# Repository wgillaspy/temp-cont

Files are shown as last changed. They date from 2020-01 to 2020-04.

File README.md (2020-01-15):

# temp(erature)-cont(roller)

An very small atemga328p based temperature controller that can be used to incubate animals :lizard: :honeybee: :hatching_chick: and plants :rose: :cactus:. 

It uses up to five ds18b20 temperature probes connected into a single audio jack to monitor temperature.
Heating can be provided through a 5v-12vDC heating source.  I use the 12v rail of a spare computer power supply.

The board connects to any computer over usb serial and prints the temperature statuses in Json about every second.  The 
default target temperature can be changed while running and is stored in EEPROM to survive power offs.  The target temperature 
can also be set without writing to EEPROM.  This is useful when using a secondary application to maintain a temperature profile.
Right now the temperature can only be set with integers.
 
Programming of the atmega is done over a mini-usb (ftdi) or via the isp headers.

##### Setting the target temperature

Set the target temperature to 91F and write the value to EEPROM to persist across power offs.
```json
{"a":"tgt","tgt":91} 
```

Set the target temperature to 100F and **do not** write the value to EEPROM.  The target temperature will revert back to what is stored in EEPROM if powered off and back on.
```json
{"a":"tgt_tmp","tgt":100}
``` 

##### Reading the output
Every second or so, the board sends a json string so you know the status of your incubator.  t0 and t1 are the two 
temperatures probes (the code allows up to five).  Avg is the probe's temperature averaged together.  It's the temperature
used to compare against the tgt value.  Ht is whether the heater mostfet is on or not.  And fan is the number of pulses received between readings.  If the pulse fall to zero, the heating element will be disabled to prevent overheating.
```json
{ "tgt": "81",
  "t0": "80.60",
  "t1": "81.50",
  "avg": "81.05",
  "ht": "0",
  "fan": "126" }
``` 

Top layer of the board, about life size.  
Board Top

The controller board is hooked up to a raspberry pi running the [nodejs controller](nodejs/src/main/controller) container which
maintains a temperature profile and sends the output of the board to a personal splunk instance for graphing.   
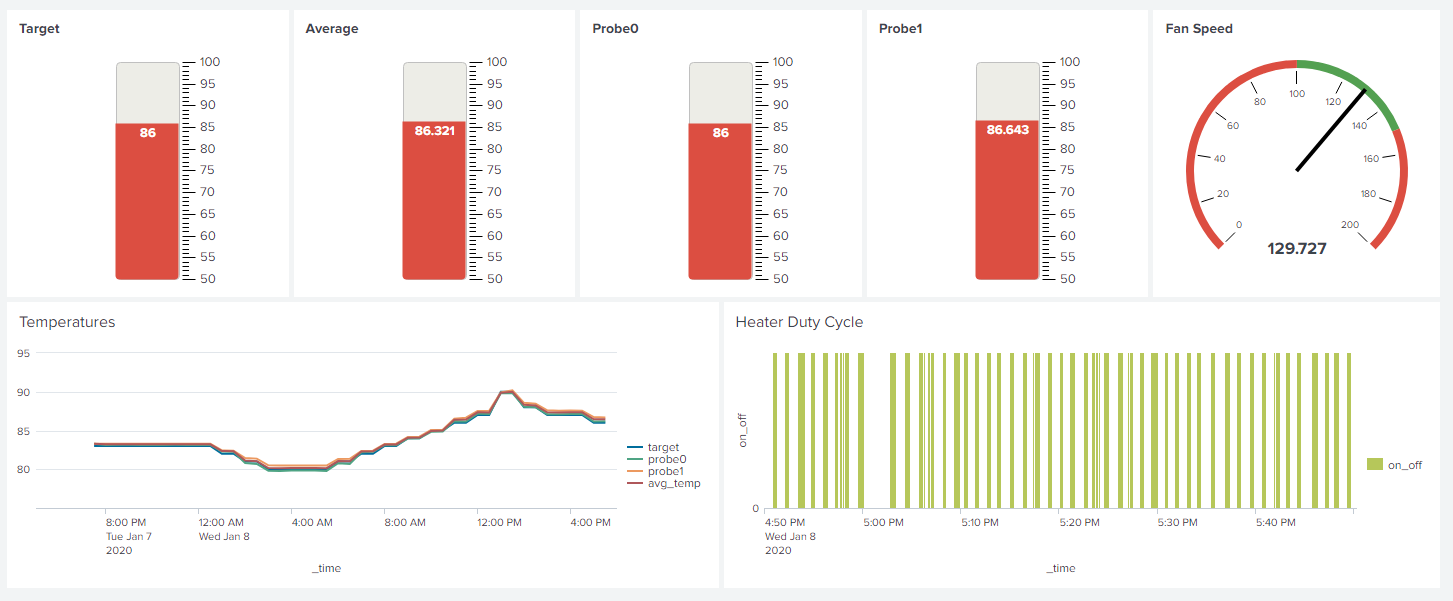
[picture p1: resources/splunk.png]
SplunkPanel


How updates are deployed.

- Board code is tested locally on the workstation and once confirmed as working then
- The code is pushed to github.
- The github webhook calls out to Jenkins on the same private network as the temperature controller.
- The Jenkins instance creates a build container
- The build container then packages up the arduino code into an [avr-dude container](https://github.com/wgillaspy/arm64v8-avrdude) and sends it to a raspberry pi that the temperature controller is connected to via usb.
- The build container requests that the container start then
- At container start, the temperature controller code is compiled within the avr-dude container on the remote raspberry pi and then deployed to the temperature controller board.

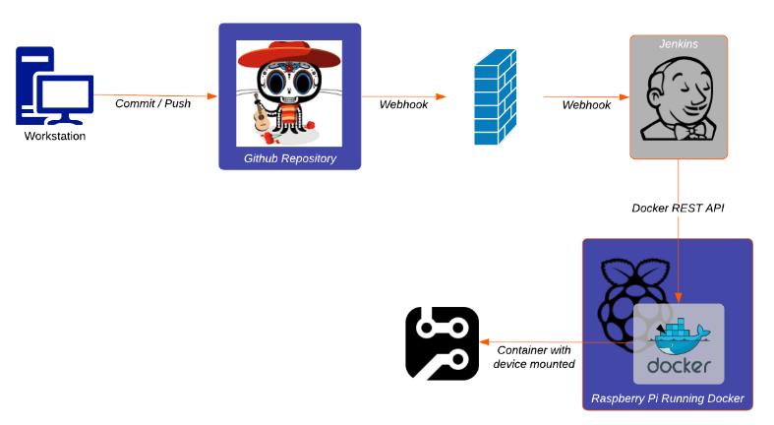
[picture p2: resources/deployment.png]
Deploy


Why the additional complexity with docker?  Mostly to take advantage of an immutable system that is easy to recover.
If the raspberry pi SD fails (which they infrequently do) I can quickly stand up a new raspberry pi with the docker REST api exposed using a simple ansible script.
Once the REST api is exposed and the raspberry pi is placed back on the network, jenkins can deploy both the temperature controller board code (if necessary) and the application that manages the temperature profile.

Since I don't keep my incubator near my workstation, having a deployment pipeline that can update both the firmware and
secondary application that controls the temperature profile to remote locations is super awesome.  I don't have to lug
my laptop around just to add a feature or set a default temperature.

Hopefully some portion of this project will be useful to you :)  

#### New Things
- [x] Add SMS notifications.
- [x] Update the NodeJs application to write to a splunk endpoint. 

#### :building_construction: Board changes.
- [x] Remove the serial display jumper in favor of another 5V fan jumper.  
- [x] Add an additional mosfet for the additional fan.
- [x] Better isolate the two fan jumpers, provide their own 5v separate from atmega board to reduce noise.  
- [x] Move the mosfet gate pins onto analog output pins.  Right now the heater can only be off or on.
- [x] Remove the ftdi programmer pads from the bottom of the board.
- [x] Add a jumper for the heater mosfet gate that can be used to drive an external AC mosfet. (feature/new-board-layout)

#### Upcoming board changes
- [ ] Convert the mini usb connector to usb c.
- [ ] Update the BOM and pad sizes to be consistent across components.
- [ ] Does 0402 makes sense?  
- [ ] Retrace the board to reduce overall board size.
- [ ] Figure out compatibility issues with atmega328pb

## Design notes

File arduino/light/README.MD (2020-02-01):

Analog Out / TIMER / PWM Pins

- 2  PD2 - FAN INT 1
- 3  PD3 - FAN INT 2
- 5  PD5 - HEATER GATE
- 6  PD6 - FAN GATE 1
- 9  PB1 - FAN GATE 2
- 10 PB2 - SS
- 11 PB3 - MOSI

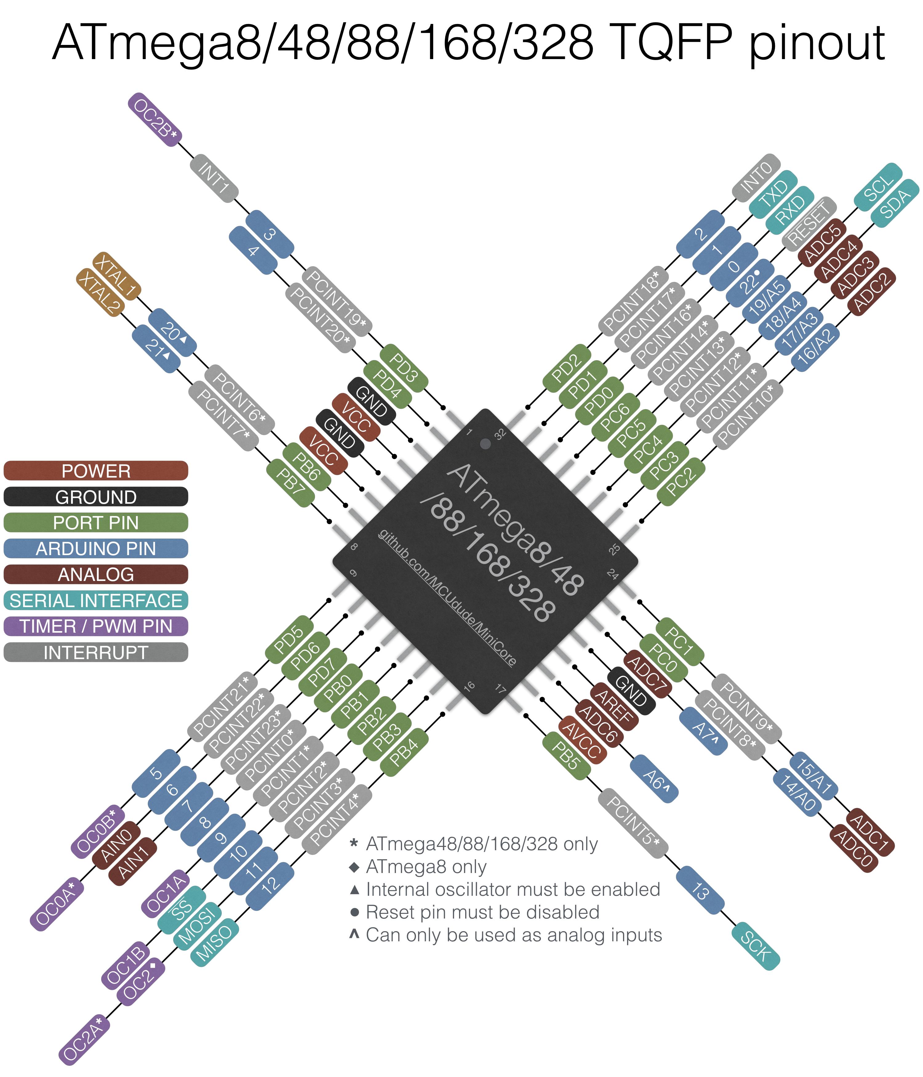
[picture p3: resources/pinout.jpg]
Atmega8


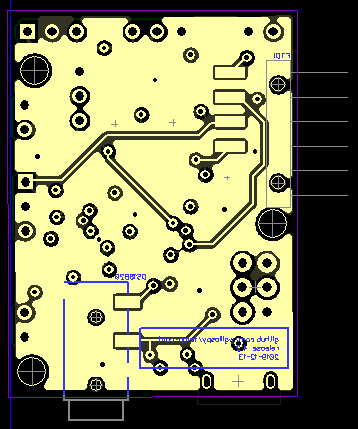
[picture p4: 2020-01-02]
resources/board-bottom.png

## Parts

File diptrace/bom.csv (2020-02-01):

Manufacturer | Name | Value | RefDes
 | JUMPER_2 |  | 12VDrain
 | JUMPER_3 |  | 5VFan
 | JUMPER_3 |  | 5VFan1
 | JUMPER_2 |  | 5VoltPower
Atmel | ATMEGA8_TQFP |  | ATMEGA
 | CAP0402-CAP | 0.1uF | C1
 | CAP0603-CAP | 0.1uF | C2
 | CAP0402-CAP | 0.1uF | C4
 | CAP0402-CAP | 10uF | C5
 | CAP0402-CAP | 10uF | C6
 | AUDIO-JACK3 | AUDIO-JACK3 | DS18B20
 | JUMPER_2 |  | ExtGate
 | JUMPER_3 |  | FANMOSFET
 | JUMPER_3 |  | FANMOSFET1
 | JUMPER_3 |  | HEATERMOSFET
 | AVR_SPI_PRG_6SMT_MALE | ICSP | ISP
 | LED_0603 | Blue | LED1
 | LED_0603 | Green | LED2
 | LED_0603 | Blue | LED3
 | LED_0603 | Blue | LED4
 | LED0603 (LED) | Red | LED5
 | LED0603 (LED) | Green | LED6
 | RESISTOR0402-RES | 10K | R1
 | RESISTOR0603-RES | 1k | R2
 | RESISTOR0603-RES | 1k | R3
 | RESISTOR0603-RES | 1k | R4
 | RESISTOR0603-RES | 1k | R5
 | RESISTOR0603-RES | 1k | R6
 | RESISTOR0603-RES | 1k | R7
 | RESISTOR0603-RES | 1k | R8
 | RESISTOR0603-RES (RESISTOR) | 1K | R9
 | RESISTOR0603-RES (RESISTOR) | 1K | R10
 | RES_0402 |  | R4.7K2
 | FT232RLSSOP (FT232RL) |  | U2
 | USB MICRO 609-4616-1 |  | U4
 | JUMPER_2 |  | VCC_FAN/GND
 | RESONATORSMD | 10k | Y1

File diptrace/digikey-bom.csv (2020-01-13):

Manufacturer Part Number | Manufacturer | Digi-Key Part Number | Customer Reference | Reference Designator | Packaging | Part Status | Quantity | Unit Price | Extended Price | Description | RoHS Status | Lead Free Status
C1608JB0J106K080AB | TDK Corporation | 445-11185-1-ND |  |  | Cut Tape (CT) | Active | 2 | 0.41 | $0.82 | CAP CER 10UF 6.3V JB 0603 | ROHS3 Compliant | Lead free
CL05A104MP5NNNC | Samsung Electro-Mechanics | 1276-1443-1-ND |  |  | Cut Tape (CT) | Active | 4 | 0.1 | $0.40 | CAP CER 0.1UF 10V X5R 0402 | ROHS3 Compliant | Lead free
CSTNE16M0VH3C000R0 | Murata Electronics | 490-17951-1-ND |  |  | Cut Tape (CT) | Active | 1 | 0.44 | $0.44 | CERAMIC RES 16.0000MHZ 15PF SMD | ROHS3 Compliant | Contains lead
FT232RL-REEL | FTDI, Future Technology Devices International Ltd | 768-1007-1-ND |  |  | Cut Tape (CT) | Active | 1 | 4.5 | $4.50 | IC USB FS SERIAL UART 28-SSOP | RoHS Compliant | Lead free
ERA-2AED103X | Panasonic Electronic Components | P10KDECT-ND |  |  | Cut Tape (CT) | Active | 2 | 0.22 | $0.44 | RES SMD 10K OHM 0.5% 1/16W 0402 | ROHS3 Compliant | Lead free
ERA-3AED102V | Panasonic Electronic Components | P123733CT-ND |  |  | Cut Tape (CT) | Active | 8 | 0.11 | $0.88 | RES SMD 1K OHM 0.5% 1/10W 0603 | ROHS3 Compliant | Lead free
10118193-0001LF | Amphenol ICC (FCI) | 609-4616-1-ND |  |  | Cut Tape (CT) | Active | 1 | 0.43 | $0.43 | CONN RCPT USB2.0 MICRO B SMD R/A | RoHS Compliant | Lead free
ERJ-3GEYJ472V | Panasonic Electronic Components | P4.7KGCT-ND |  |  | Cut Tape (CT) | Active | 1 | 0.1 | $0.10 | RES SMD 4.7K OHM 5% 1/10W 0603 | ROHS3 Compliant | Lead free
ATMEGA328P-AUR | Microchip Technology | ATMEGA328P-AURCT-ND |  |  | Cut Tape (CT) | Active | 1 | 2.08 | $2.08 | IC MCU 8BIT 32KB FLASH 32TQFP | ROHS3 Compliant | Lead free
IN-S63AT5B | Inolux | 1830-1061-1-ND |  |  | Cut Tape (CT) | Active | 1 | 0.34 | $0.34 | LED BLUE CLEAR 0603 SMD | ROHS3 Compliant | Lead free
IN-S63AT5G | Inolux | 1830-1062-1-ND |  |  | Cut Tape (CT) | Active | 2 | 0.52 | $1.04 | LED GREEN CLEAR 0603 SMD | ROHS3 Compliant | Lead free
IN-S63AT5Y | Inolux | 1830-1066-1-ND |  |  | Cut Tape (CT) | Active | 1 | 0.32 | $0.32 | LED YELLOW CLEAR 0603 SMD | ROHS3 Compliant | Lead free
IN-S63ATR | Inolux | 1830-1065-1-ND |  |  | Cut Tape (CT) | Active | 1 | 0.34 | $0.34 | LED RED CLEAR 0603 SMD | ROHS3 Compliant | Lead free
LO Q976-PS-25-0-20-R18 | OSRAM Opto Semiconductors Inc. | 475-2486-1-ND |  |  | Cut Tape (CT) | Active | 1 | 0.29 | $0.29 | LED ORANGE DIFFUSED 0603 SMD | ROHS3 Compliant | Lead free
FQP30N06L | ON Semiconductor | FQP30N06L-ND |  |  | Tube | Active | 3 | 1.22 | $3.66 | MOSFET N-CH 60V 32A TO-220 | ROHS3 Compliant | Lead free

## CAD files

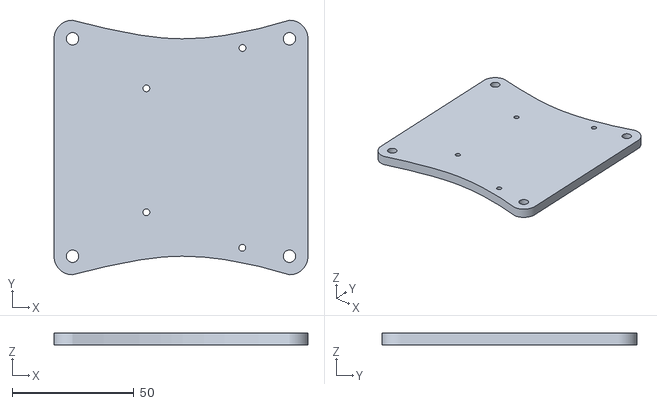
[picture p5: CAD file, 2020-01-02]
parts/new_stl/HangingMount.stl
104.3 x 104.5 x 5.08

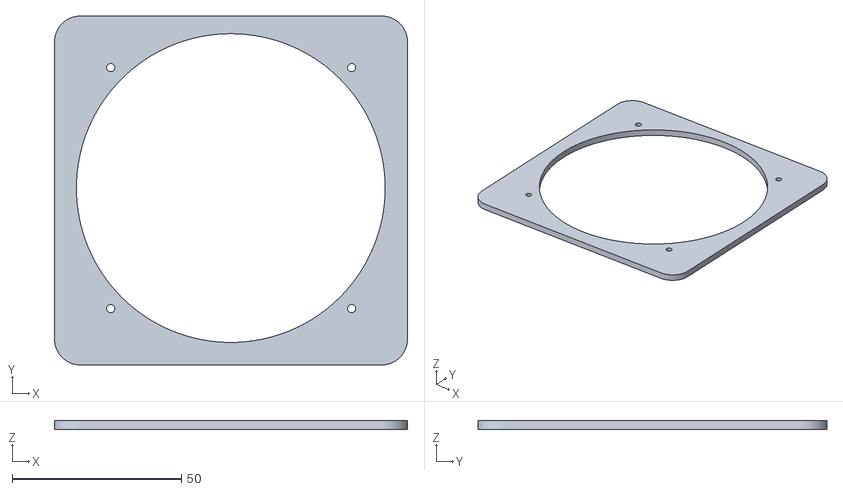
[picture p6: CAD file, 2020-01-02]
parts/new_stl/SHLargeFanTop.stl
104.2 x 103.0 x 2.54

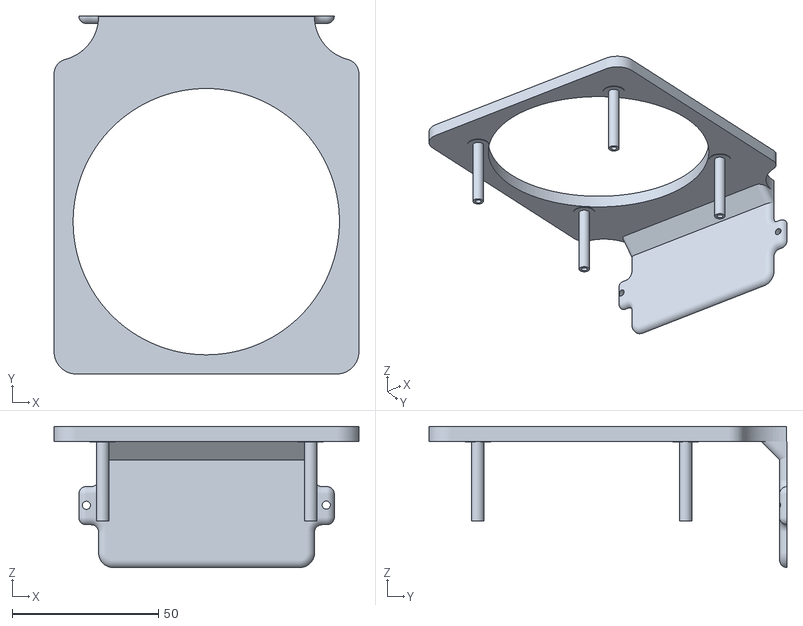
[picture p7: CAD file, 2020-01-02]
parts/new_stl/HeaterBaseInternal.stl
104.3 x 122.4 x 48.3

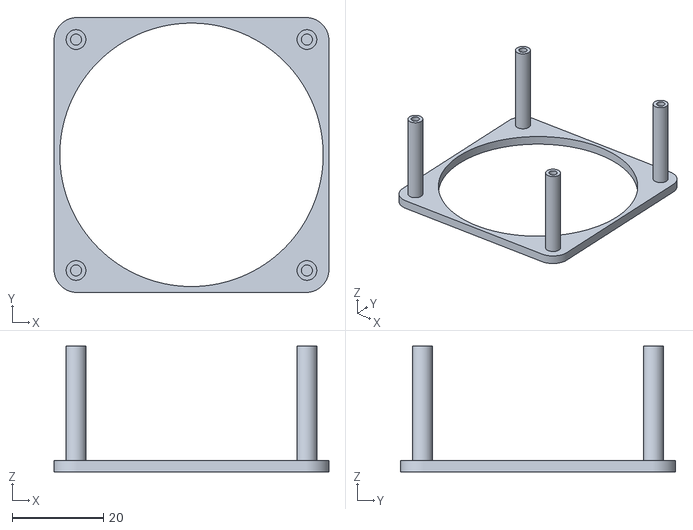
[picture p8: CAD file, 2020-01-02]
parts/new_stl/SHFanHolder.stl
60.2 x 60.2 x 27.6

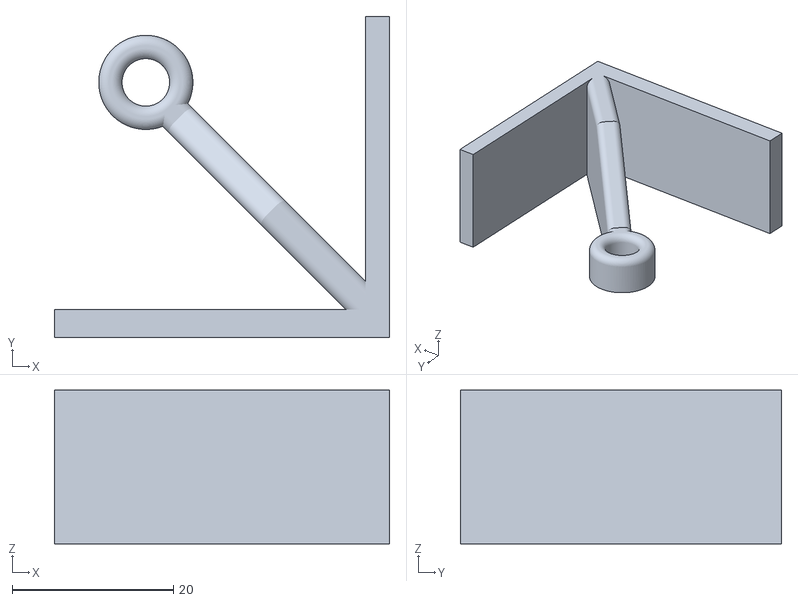
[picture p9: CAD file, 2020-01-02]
parts/new_stl/TempProbeHolder.stl
41.6 x 39.8 x 19.0

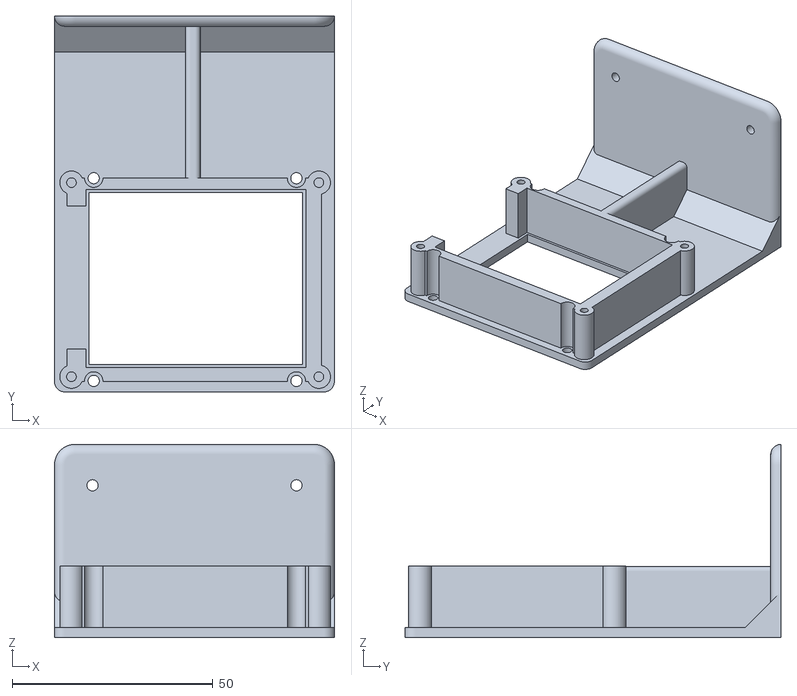
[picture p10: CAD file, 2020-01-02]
parts/new_stl/SHHeatElementHolder.stl
69.8 x 93.7 x 48.2

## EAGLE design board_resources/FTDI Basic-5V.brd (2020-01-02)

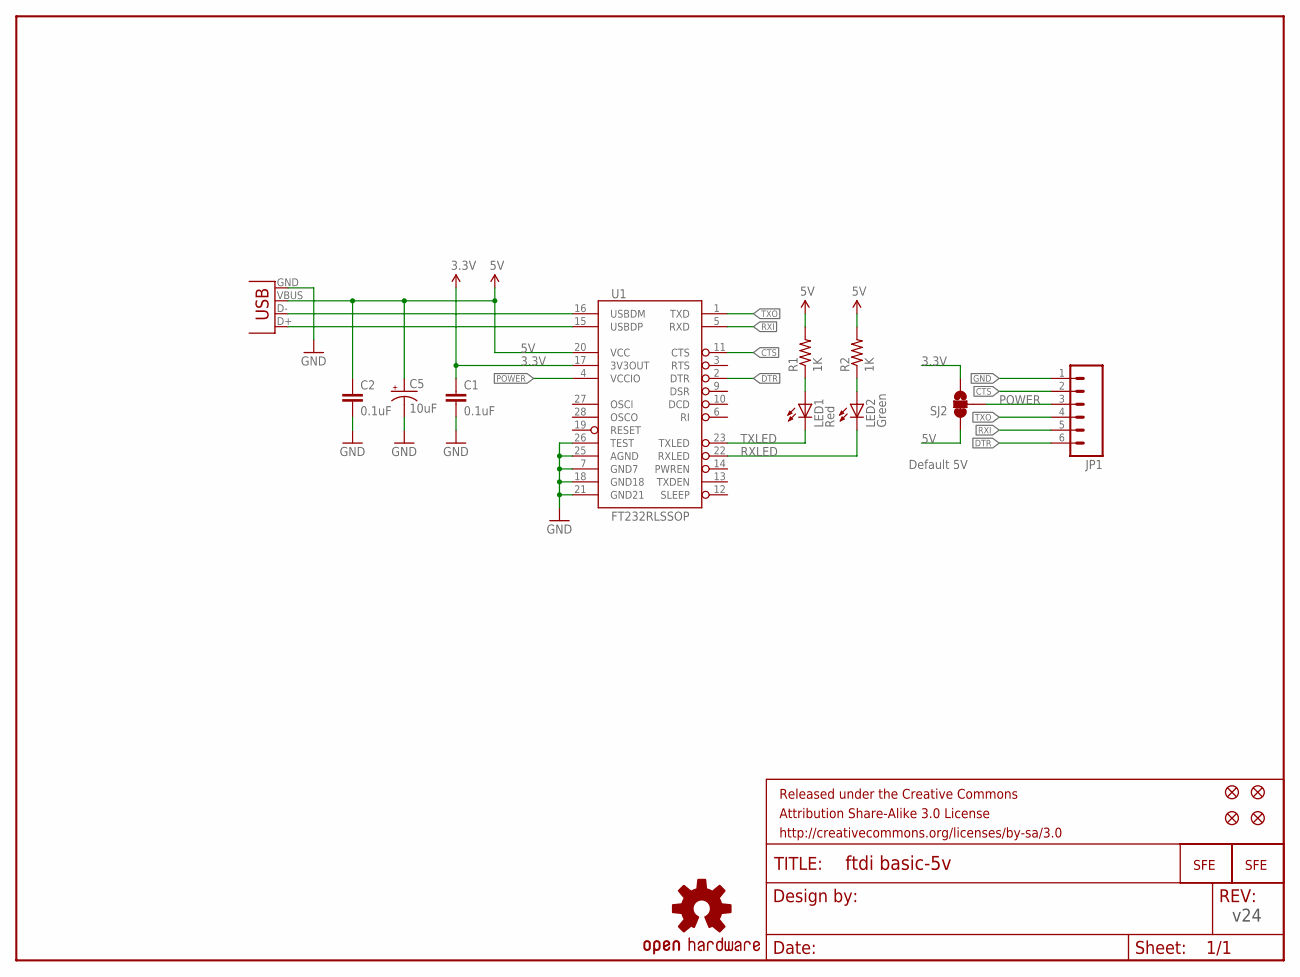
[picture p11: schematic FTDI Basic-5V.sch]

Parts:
C1, C2: 0.1uF; 0603-CAP
C5: 10uF; EIA3216
FRAME1: FRAME-LETTER; CREATIVE_COMMONS
JP1: M06SMD-FEMALE-V2; 1X06-SMD-FEMALE-V2
JP2: LOGO-SFESK; SFE-LOGO-FLAME
JP3, JP4, JP5, JP6: FIDUCIAL1X2; FIDUCIAL-1X2
LED1: Red; LED-0603
LED2: Green; LED-0603
LOGO1: OSHW-LOGOS; OSHW-LOGO-S
R1, R2: 1K; 0603-RES
SJ2: SOLDERJUMPER_2WAYS; SJ_3
U1: FT232RLSSOP; SSOP28DB
U$2: LOGO-SFENW2; SFE-NEW-WEB
X2: USB-SMD-NS; USB-MINIB-NOSTOP

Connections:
3.3V: C1.1, SJ2.3, U1.17 (3V3OUT)
5V: C2.1, C5.A (+), R1.2, R2.2, SJ2.1, U1.20 (VCC), X2.VBUS
CTS: JP1.2, U1.11 (CTS)
DTR: JP1.6, U1.2 (DTR)
GND: C1.2, C2.2, C5.C (-), JP1.1, U1.7 (GND7), U1.18 (GND18), U1.21 (GND21), U1.25 (AGND), U1.26 (TEST), X2.GND
unnamed: LED1.A, R1.1
unnamed: LED2.A, R2.1
POWER: JP1.3, SJ2.2, U1.4 (VCCIO)
RXI: JP1.5, U1.5 (RXD)
RXLED: LED2.C, U1.22 (RXLED)
TXLED: LED1.C, U1.23 (TXLED)
TXO: JP1.4, U1.1 (TXD)
USB_D+: U1.15 (USBDP), X2.D+
USB_D-: U1.16 (USBDM), X2.D-

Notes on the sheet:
Default 5V
v24

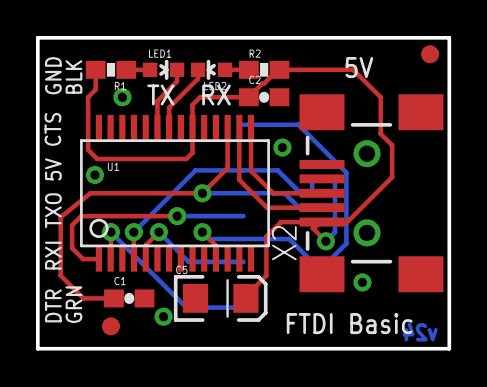
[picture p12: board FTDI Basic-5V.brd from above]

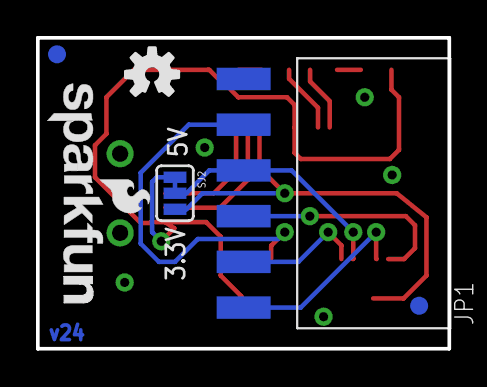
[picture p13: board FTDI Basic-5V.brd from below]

Board: 2 copper layers, 22.9 x 17.3 mm, 19 parts (7 on the bottom side), 14 nets.

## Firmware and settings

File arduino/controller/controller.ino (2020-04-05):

/** 
 *  Commands currently accepted by this program.
 *  {"a":"tgt","tgt":91}  # Set the temperature and write the value to eeprom to persist across power offs.
 *  {"a":"tgt_tmp","tgt":100} # Set the temperature temporarily.  Value will revert to what is stored in eeprom if powered off.
 *  Use this to mimic temperature changes during the day and night for animals, plants, etc.
 *  Compatible with revision 4.5.*
**/
#include <ArduinoJson.h>
#include <OneWire.h>
#include <DallasTemperature.h>
#include <EEPROM.h>

#define ONE_WIRE_BUS 4

#define STATUS_LED_1 14  // RED LED
#define STATUS_LED_2 15  // BLUE LED
#define STATUS_LED_3 13  // BLUE LED

#define MOSFET_HEAT 5
#define MOSFET_FAN_1 6
#define MOSFET_FAN_2 9

#define TARGET_TEMP_EEPROM_ADDRESS 0
#define TARGET_TEMP 85 // Target temperature cannot be a decimal at this time.
#define MAX_TARGET_TEMP 120 // Don't let the temperature be set above this amount.

#define READ_DELAY 200

#define INTERRUPT_PIN_FAN_1 2
#define INTERRUPT_PIN_FAN_2 3

#define DUTY_CYCLE_ON 4
#define DUTY_CYCLE_OFF 8

// Hold up to 5 temperature probes.  Add more if you need them.
byte oneWireAddresses[5][8];
// The index that we can count to.  Can't push arrays around these parts.
int  oneWireMaxIndex = 0;

boolean mosfetOn_heater = false;
int mosfetDutyCycleOnCount = 0;
int mosfetDutyCycleOffCount = 0;


boolean mosfetOn_fan = false;

boolean fanIsRunning = false;

int mosfetValue_heater = 0;
int mosfetValue_fan = 0;

int persistentTargetTemperature = TARGET_TEMP;

// Each DS18B20 has it's own one wire address.  Visit http://www.hacktronics.com/Tutorials/arduino-1-wire-address-finder.html
// Make sure you have your 4.7K resistor on data and +5V.
OneWire oneWire(ONE_WIRE_BUS);
DallasTemperature sensors(&oneWire);

volatile int fanInterruptCount = 0;

void readRpm() {
  fanInterruptCount++;
}

void blinkLED(int PIN) {
  digitalWrite(PIN, HIGH);
  delay(READ_DELAY);
  digitalWrite(PIN, LOW);
}

void readJsonAndDoAction(String inputJson) {
    StaticJsonDocument<400> doc;
    DeserializationError error = deserializeJson(doc, inputJson);
    // Test if parsing succeeds.
    if (error) {
      Serial.print(F("deserializeJson() failed: "));
      Serial.println(error.c_str());
      return;
    }
    
    String action = doc["a"];
    if (action.equals("tgt")) {
      int newTargetTemperature = doc["tgt"];
      setAndReadTargetTemperature(newTargetTemperature, true);
    }
    if (action.equals("tgt_tmp")) {
      int newTargetTemperature = doc["tgt"];
      if (newTargetTemperature < MAX_TARGET_TEMP) {
         persistentTargetTemperature = newTargetTemperature;  
      }
    }
}

void setAndReadTargetTemperature(int temperature, boolean overwrite) {
  
  int storedTargetTemperature = EEPROM.read(TARGET_TEMP_EEPROM_ADDRESS);
  if (storedTargetTemperature == 255 || overwrite) { // The EEPROM hasn't been set.
    if (temperature > MAX_TARGET_TEMP) { // Don't allow the target temperature to exceed the maximum temperature.
      temperature = MAX_TARGET_TEMP;
    }
    EEPROM.write(TARGET_TEMP_EEPROM_ADDRESS, temperature);
    persistentTargetTemperature = temperature;
  } else {
    if (storedTargetTemperature < MAX_TARGET_TEMP) { //   Nothing I do needs to be above this temperature.
      persistentTargetTemperature = storedTargetTemperature;
    }
  }
}

void setup() {

  Serial.begin(9600);

  setAndReadTargetTemperature(TARGET_TEMP, false);

  int storedTargetTemperature = EEPROM.read(TARGET_TEMP_EEPROM_ADDRESS);
  if (storedTargetTemperature == 255) {// The EEPROM hasn't been set.
     EEPROM.write(TARGET_TEMP_EEPROM_ADDRESS, TARGET_TEMP);
  } else {
    if (storedTargetTemperature < 120) { //   Nothing I do needs to be above this temperature.
      persistentTargetTemperature = storedTargetTemperature;
    }
  }
  
  discoverOneWireDevices();
  sensors.begin();

    for( int i = 0; i < oneWireMaxIndex; i++) {
      sensors.setResolution(oneWireAddresses[i], 8);
    }

    pinMode(STATUS_LED_1, OUTPUT);
    pinMode(STATUS_LED_2, OUTPUT);
    pinMode(STATUS_LED_3, OUTPUT);

    digitalWrite(STATUS_LED_1, LOW);
    digitalWrite(STATUS_LED_2, LOW);
    digitalWrite(STATUS_LED_3, LOW);

    // The heater mosfet must be written low on startup.
    // Otherwise a power failure while it's above temperature will leave
    // heater element on and overheat the device.
    pinMode(MOSFET_HEAT, OUTPUT);
    analogWrite(MOSFET_HEAT, 0);


    // The fan mosfet should be written high on startup.
    pinMode(MOSFET_FAN_1, OUTPUT);
    analogWrite(MOSFET_FAN_1, 255);

    pinMode(MOSFET_FAN_2, OUTPUT);
    analogWrite(MOSFET_FAN_2, 255);

    pinMode(INTERRUPT_PIN_FAN_1, INPUT);
    digitalWrite(INTERRUPT_PIN_FAN_1, HIGH);

    attachInterrupt(digitalPinToInterrupt(INTERRUPT_PIN_FAN_1), readRpm, RISING);

    blinkLED(STATUS_LED_1);
    blinkLED(STATUS_LED_2);
    blinkLED(STATUS_LED_3);

    delay(500); // Let the fan spin up.
    checkFanStatus(); // Preload the fan status so that it doesn't show an error on startup.
    
    blinkLED(STATUS_LED_1);
    blinkLED(STATUS_LED_2);
    blinkLED(STATUS_LED_3);
    
}

String addToJsonString(String json, String add_json) {
  if (json.length() == 0) {
     return "{" + add_json + "}";
  } else {
    json.remove(json.length() - 1);
    return json + "," + add_json + "}";
  }
}

void checkFanStatus() {
   // Make sure the fan is running.  If it's not, turn off the heat.
  if (fanInterruptCount > 8) {
    blinkLED(STATUS_LED_2);
    fanIsRunning = true;
  } else {
    digitalWrite(STATUS_LED_2, LOW);
    fanIsRunning = false;
  }
 
  fanInterruptCount = 0;
}

void loop() {
  if (Serial.available() > 0) {
    // read the incoming byte:
    String incomingJson = Serial.readString();
    readJsonAndDoAction(incomingJson);
  }

  sensors.requestTemperatures();
  double combinedTemperatures = 0.0;

  String jsonStringToPrint = "";
  String persistentTargetTemperatureString = getJsonPair("tgt", persistentTargetTemperature);
  jsonStringToPrint = addToJsonString(jsonStringToPrint, persistentTargetTemperatureString);
  
  for(int i = 0; i < oneWireMaxIndex; i++) {
    double temperature = readTemp(oneWireAddresses[i]);
    combinedTemperatures += temperature;

    String name = "t" + String(i);
    String probeTempString = getJsonPair(name, temperature);
    jsonStringToPrint = addToJsonString(jsonStringToPrint, probeTempString);
  }

  double average = combinedTemperatures / oneWireMaxIndex;
  String probeAverageString = getJsonPair("avg", average);
  jsonStringToPrint = addToJsonString(jsonStringToPrint, probeAverageString);

//  if (fanIsRunning) {

    if (average > persistentTargetTemperature) {

      if (mosfetOn_heater) {
        rampDownMosfet(MOSFET_HEAT);
        rampDownMosfet(MOSFET_FAN_1, 0);
        rampDownMosfet(MOSFET_FAN_2, 0);
        digitalWrite(STATUS_LED_3, LOW);
        mosfetOn_heater = false;
        mosfetDutyCycleOnCount = 0;
        mosfetDutyCycleOnCount = 0;
      }

    } else if (average <= persistentTargetTemperature) {
      if (!mosfetOn_heater) {
        rampUpMosfet(MOSFET_FAN_1);
        rampUpMosfet(MOSFET_FAN_2);
        rampUpMosfet(MOSFET_HEAT);
        digitalWrite(STATUS_LED_3, HIGH);
        mosfetOn_heater = true;
      } 
      if (mosfetOn_heater) {
      
          if (mosfetDutyCycleOnCount < DUTY_CYCLE_ON) {
              mosfetDutyCycleOnCount += 1; 
          } else {
              rampDownMosfet(MOSFET_HEAT);
          }
         
         if (mosfetDutyCycleOnCount >= DUTY_CYCLE_ON) {
          if (mosfetDutyCycleOffCount < DUTY_CYCLE_OFF) {
             mosfetDutyCycleOffCount += 1;
          } else {
             rampUpMosfet(MOSFET_HEAT);
             mosfetDutyCycleOnCount = 0;
             mosfetDutyCycleOffCount = 0;
          }
         }
      }
    }
//  } else {
//    //Serial.println("Status: Fan is not running. Forcing heat off.");
//    String errorPair = getJsonPair("err","fan");
//    jsonStringToPrint = addToJsonString(jsonStringToPrint, errorPair);
//    analogWrite(MOSFET_HEAT, 0);
//    mosfetOn_heater = false;
//    blinkLED(STATUS_LED_3);
//    blinkLED(STATUS_LED_3);
//    blinkLED(STATUS_LED_3);
//  }

  String mosfetStatusPair = getJsonPair("ht", mosfetOn_heater ? 1 : 0 );
  jsonStringToPrint = addToJsonString(jsonStringToPrint, mosfetStatusPair);

  String fanPair = getJsonPair("fan", fanInterruptCount);
  jsonStringToPrint = addToJsonString(jsonStringToPrint, fanPair);

  checkFanStatus();

  // Indicate a loop with a blink.
  blinkLED(STATUS_LED_1);

  Serial.println(jsonStringToPrint);

  delay(800);
}

void rampUpMosfet(int MOSFET_PIN) {
//  for (int i = 0; i <= 255; i += 5) {
//    analogWrite(MOSFET_PIN, i);
//    delay(10);
//  }
  analogWrite(MOSFET_PIN, 255);
}

void rampDownMosfet(int MOSFET_PIN) {
//  for (int i = 255; i >= 0; i -= 5) {
//    analogWrite(MOSFET_PIN, i);
//    delay(10);
//  }
  analogWrite(MOSFET_PIN, 0);
}

void rampDownMosfet(int MOSFET_PIN, int value) {
//  for (int i = 255; i >= 0; i -= 5) {
//    analogWrite(MOSFET_PIN, i);
//    delay(10);
//  }
  analogWrite(MOSFET_PIN, value);
}

void discoverOneWireDevices(void) {
  byte i;
  byte addr[8];

  while(oneWire.search(addr)) {

    for( i = 0; i < 8; i++) {
      oneWireAddresses[oneWireMaxIndex][i] = addr[i];
    }

    oneWireMaxIndex++;

    if ( OneWire::crc8( addr, 7) != addr[7]) {
      // CRC is not valid.
      return;
    }
  }

  oneWire.reset_search();

  return;
}

String doubleToString(double input,int decimalPlaces) {
  if(decimalPlaces!=0) {
    String string = String((int)(input*pow(10,decimalPlaces)));

    if(abs(input)<1) {
      if(input>0) {
       string = "0"+string;
      } else if(input<0) {
       string = string.substring(0,1)+"0"+string.substring(1);
      }
    }
    return string.substring(0,string.length()-decimalPlaces)+"."+string.substring(string.length()-decimalPlaces);
  } else {
    return String((int)input);
  }
}

String getJsonPair(String name, String value) {
  String json = "\"" + name + "\":\"";
  json.concat(value);
  json.concat("\"");
  return json;
}


String getJsonPair(String name, float value) {
  String json = "\"" + name + "\":\"";
  json.concat(value);
  json.concat("\"");
  return json;
}

String getJsonPair(String name, double value) {
  String json = "\"" + name + "\":\"";
  json.concat(value);
  json.concat("\"");
  return json;
}

String getJsonPair(String name, int value) {
  String json = "\"" + name + "\":\"";
  json.concat(value);
  json.concat("\"");
  return json;
}


float readTemp(DeviceAddress deviceAddress) {
  float tempC = (float)sensors.getTempF(deviceAddress);
  if (tempC == -127.00) {
    //Serial.print("Error getting temperature");
  } 
  return tempC;
}

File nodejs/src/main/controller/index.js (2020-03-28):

// 9
const SerialPort = require('serialport');
const Readline = require('@serialport/parser-readline');
const moment = require('moment');
const axios = require("axios");


const lightControllerPort = new SerialPort('/dev/lightController', {
    baudRate: 9600
});

const temperatureControllerPort = new SerialPort('/dev/tempController', {
    baudRate: 9600
});

const newTemp = {"a": "tgt_tmp", "tgt": 85};
const newLight = {"a": "tgt_light", "tgt": 0};

const temperatureMap = {
    0: 83,
    1: 83,
    2: 83,
    3: 83,
    4: 83,
    5: 83,
    6: 83,
    7: 83,
    8: 83,
    9: 84,
    10: 85,
    11: 85,
    12: 85,
    13: 85,
    14: 85,
    15: 85,
    16: 85,
    17: 85,
    18: 85,
    19: 83,
    20: 83,
    21: 83,
    22: 83,
    23: 83
};

const lightMap = {
    0: 0,
    1: 0,
    2: 0,
    3: 0,
    4: 0,
    5: 60,
    6: 70,
    7: 120,
    8: 160,
    9: 220,
    10: 220,
    11: 255,
    12: 255,
    13: 255,
    14: 255,
    15: 255,
    16: 220,
    17: 160,
    18: 120,
    19: 60,
    20: 0,
    21: 0,
    22: 0,
    23: 0
};


const lightControllerParser = lightControllerPort.pipe(new Readline({delimiter: '\r\n'}));

const temperatureControllerParser = temperatureControllerPort.pipe(new Readline({delimiter: '\r\n'}));

lightControllerParser.on('data', function (data) {
    try {
        const json = JSON.parse(data);
        writeSplunkData(json);
        checkAndWriteData("Light", "lht", lightControllerPort, newLight, json, lightMap);
    } catch (parseException) {
        console.log("Json Parse Error:");
        console.log(parseException);
    }
});


temperatureControllerParser.on('data', function (data) {
    try {
        const json = JSON.parse(data);
        //console.log(json);
        writeSplunkData(json);
        checkAndWriteData("Temperature", "tgt", temperatureControllerPort, newTemp, json, temperatureMap);
    } catch (parseException) {
        console.log("Json Parse Error:");
        console.log(parseException);
    }
});

checkAndWriteData = (label, objectName, port, writejson, json, map) => {
    try {
        const hour = moment().format("H");

        if (json[objectName] != map[hour]) {

            console.log("[" + label + "] Hour: " + hour + ", " + json[objectName] + " != " + map[hour]);
            writejson.tgt = map[hour];
            port.write(JSON.stringify(writejson), function (error) {
                if (error) {
                    console.log(error);
                }
            });
        }

    } catch (err) {
        console.log(label + "Error:");
        console.log(err)
    }
};

writeSplunkData = (json) => {

    try {
        const eventObject = {"event": json};

        const axiosConfig = {
            headers: {
                "Authorization": "Splunk " + process.env.SPLUNK_TOKEN
            }
        };

        axios.post(process.env.SPLUNK_URL, eventObject, axiosConfig).then(response => {
        }).catch(error => {
        });

    } catch (splunkWriteDataError) {
        console.log("splunkWriteDataError:");
        console.log(splunkWriteDataError)
    }
};

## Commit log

2020-01-05 Restarting docker on power cycle.
2020-01-09 - Removed serial jumper. - Added additional fan mosfet - Isolated the 5v going to the fan. - Moved the mosfet pins to analog out. - Removed the ftdi pads. - Added a jumper for an external heater rela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
2020-01-11 New board export and a digikey bom.
    [BoardOutline.gbr, Bottom.gbr, BottomAssy.gbr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]
2020-01-11 Adding a notifier that reads the splunk data and sends a sms if it finds an error.
    [index.js]
2020-01-11 Fixing registry, I think.
    [index.js]
2020-01-12 Registry fixed across all nodes?
    [index.js]
2020-01-13 Changing temperature profile. Updating sms threshold on temperature change.
2020-01-26 Changing the pins. Turning the large fan off and on at the same time as the heater mosfet.
    [bom.csv]
2020-02-01 Fixing fan pin. Prepping for a light controller.
    [index.js, light.ino]
2020-02-01 Correcting device names in nodejs app.
2020-02-01 Fixing typos. Simplifying the light controller.ino. Making the nodejs application talk to both serial ports.
    [controller.ino, index.js, light.ino]
2020-02-01 Adding lightController to devices.
2020-02-04 Upping the temperature.
2020-02-08 Lowering the temperature.
2020-02-16 Keeping circulation fan on, but at half full.
2020-04-05 Keeping fans off unless heat is on.

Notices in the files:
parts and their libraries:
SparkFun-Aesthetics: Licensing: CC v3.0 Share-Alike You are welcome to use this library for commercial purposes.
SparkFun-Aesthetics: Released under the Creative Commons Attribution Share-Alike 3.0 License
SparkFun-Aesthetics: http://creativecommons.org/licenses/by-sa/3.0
